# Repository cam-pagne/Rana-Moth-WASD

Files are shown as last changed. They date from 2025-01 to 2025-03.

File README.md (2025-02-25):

# The Rana Labs Moth (WASD Version)

WASD version of [Rana Labs'](https://github.com/rana-sylvatica) Moth, a foldable leverless controller.

<div style="display: flex;">
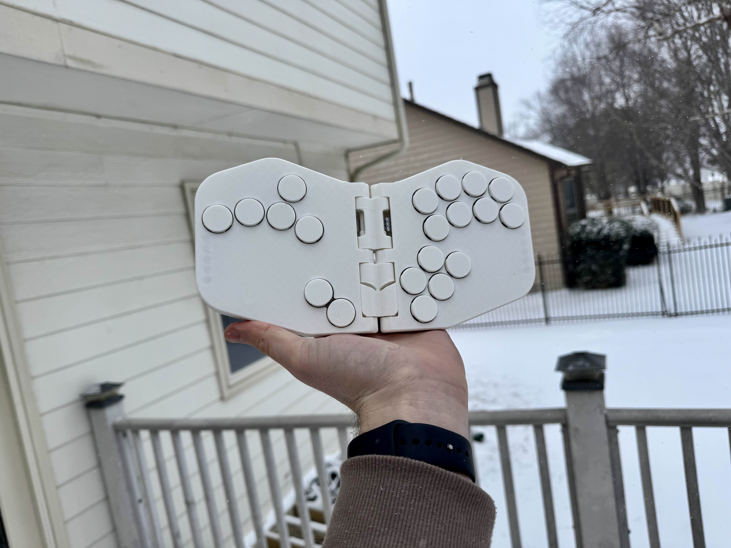
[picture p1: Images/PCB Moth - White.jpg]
Layout 1
    
</div>

---

## Build Overview (What do I need to make one?)

I printed the entire shell, hinges, etc., in **Bambu Lab Matte PLA** (though any PLA should work, build quality feel may vary).

- **Mainboards:** RP2040—**integrated directly onto the left custom PCB.** The right side is connnected by ribbon cable.
- **Switches:** Must be **low profile switches.** I use pretty much any Kailh Choc Low Profile switches. They all work, just choose a preferred switch type.
- **USB-C Connector:** [Quark's](https://github.com/quark-works) and Rana Labs' [QuRB](https://github.com/rana-sylvatica/rana-tadpole/tree/main/PCBs/Breakout%20Board%20(QuRB)), a USB C Breakout board with a ribbon cable port, for solderless assembly.
- **Hardware:** M2 screws and M3 screws are the only fasteners required to assemble. You will need **ten M3 heat inserts** for the backplates, **twelve M3 x 5/6mm bolts** for the backplates and QuRB, and **eight M2 x 4mm bolts** to secure each half of the mainboards.

---

## Assembly

### PCB

To streamline your build, I’ve designed a custom PCB for this controller. This board integrates the Pico directly eliminating the need for any handwiring of the microcontroller. The **only soldering required is the installation of the hotswap sockets for the Choc switches.**

The two halves of the board are connected using a 20 pin, .5 pitch ribbon cable, and the QuRB is connected to the Left side board for USB C port via a 12 pin, .5 pitch ribbon cable.

---

## Magnets

Strong magnets are crucial, as they must counteract every spring in your switches. I used:

- **6x3mm Neodymium magnets**, stacked **2 high** in each of the **10 total holes** (20 magnets overall).
- This setup creates a satisfying snap and keeps the Moth securely folded.

**Amazon link:** [Magnets used](https://www.amazon.com/dp/B096LZNZTQ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)

---

## 'Prism' Ergonomic Mode

For the reverse folded position:

- A **lip** on the two hinge pieces prevents overfolding by creating a defined stopping point.
- The rounded back of the hinges generates friction, ensuring rigidity in the ergonomic 'prism' configuration.

### Adjustments:

- The hinge lip’s width can be edited to modify the folding angle.

---

## Miscellaneous Notes

- **Button Fit:** Ensure buttons sit flush with the face surface when pressed to allow proper folding.
- **Magnet Strength:** Although strong neodymium magnets can overcome minor misalignments, aim for a flush fit.
- **Hinge Pin Slot:** While you can add caps for a cleaner look, the friction fit alone holds securely.

---

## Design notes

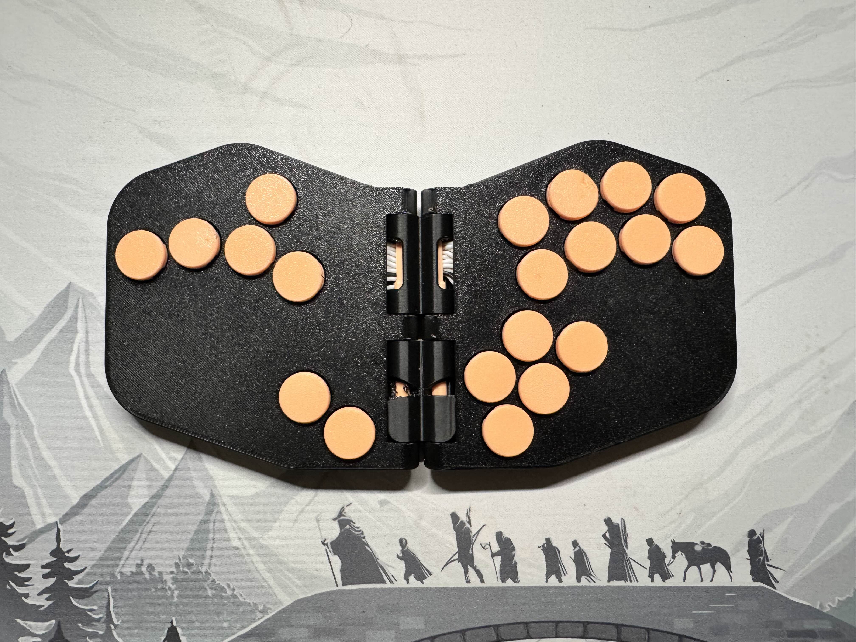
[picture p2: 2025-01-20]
Images/Layout.jpg

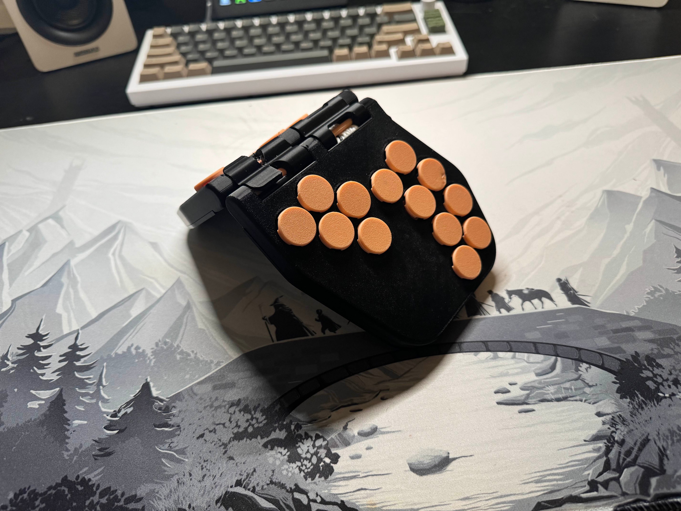
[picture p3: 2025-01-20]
Images/Folded.jpg

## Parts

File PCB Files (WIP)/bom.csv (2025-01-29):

Designator | Footprint | Quantity | Value | LCSC Part #
C1, C10, C2, C4 | 402 | 4 | 1uF | C52923
C11, C12, C13, C14, C15, C16, C17, C3, C5, C6 | 402 | 10 | 100nF | C1525
C7, C8 | 402 | 2 | 22pF | C1555
C9 | 402 | 1 | 10uF | C15525
D1 | D_SOD-123 | 1 | Schottky Diode | C8598
D3 | 805 | 1 | RED | C84256
R10, R11 | 402 | 2 | 1k | C11702
R4 | 402 | 1 | 470 | C25117
R5 | 603 | 1 | 5.6k | C23189
R6 | 603 | 1 | 10k | C25804
R7 | 402 | 1 | 10k | C25744
R8, R9 | RP2040-QFN-56 | 2 | 27 | C25190
SW1 | SW_SPST_SKQG_WithStem | 1 | Boot | C318884
U1 | SOT-23 | 1 | XC6206 | C5446
U2 | FPC-SMD_X05A26H12G | 1 | X05A26H12G | C519263
U3 | RP2040-QFN-56 | 1 | RP2040 | C2040
U4 | SOIC-8_5.23x5.23mm_P1.27mm | 1 | W25Q128JVS | C97521
Y1 | Crystal_SMD_3225-4Pin_3.2x2.5mm | 1 | 12MHz | C9002
J4, J5 | XUNPU FPC-05F-20PH20 | 2 | FPC-05F-20PH20 | C2856803

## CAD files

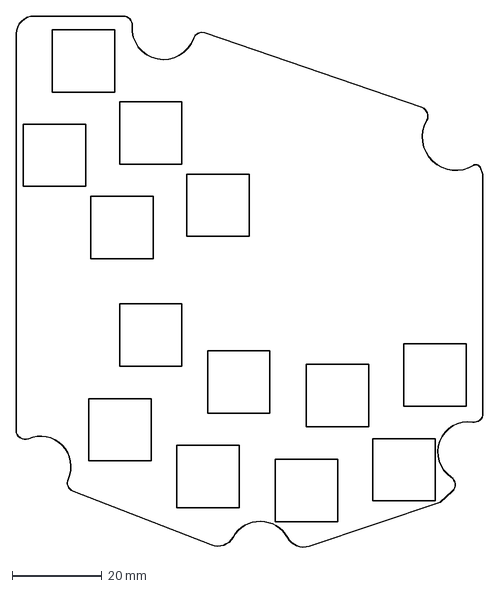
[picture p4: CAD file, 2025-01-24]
DXFs/Right PCB (Button Outlines).dxf
104.0 x 118.7 mm

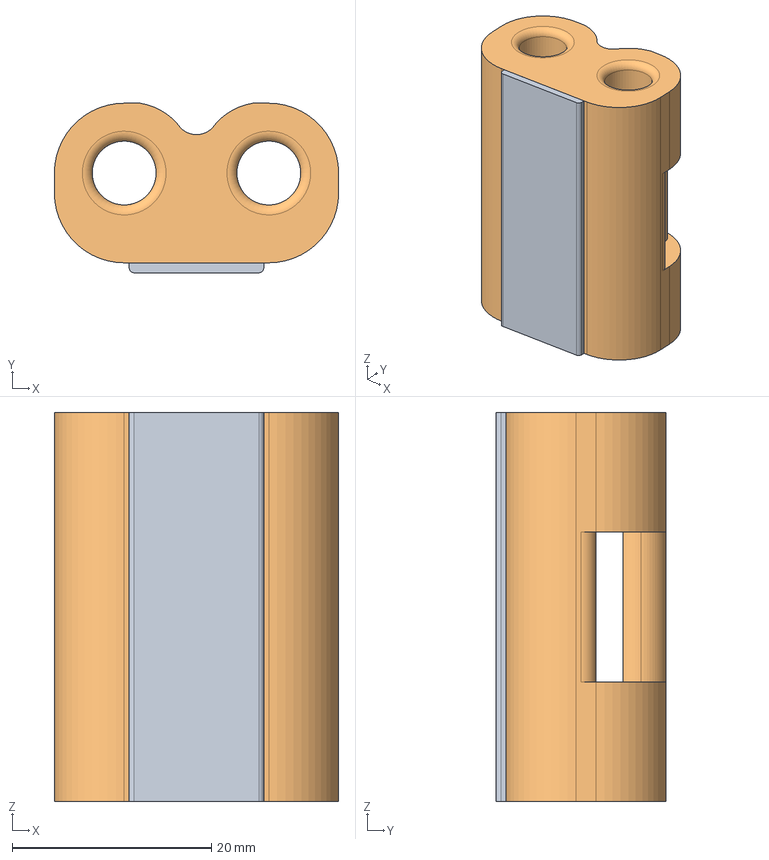
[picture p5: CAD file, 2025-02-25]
Hinge and Buttons/Hinge Upper.step
28.5 x 17.0 x 39.0 mm

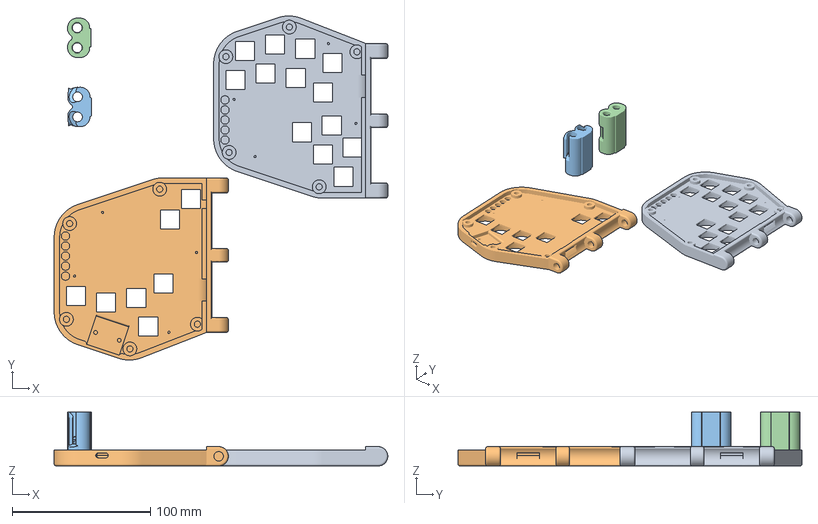
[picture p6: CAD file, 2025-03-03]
Shell/Top Shell and Hinges.3mf
241.3 x 248.8 x 39.0 mm
Moth Top Right.step
Moth Top Left.step
Hinge Lower.step
Hinge Upper.step

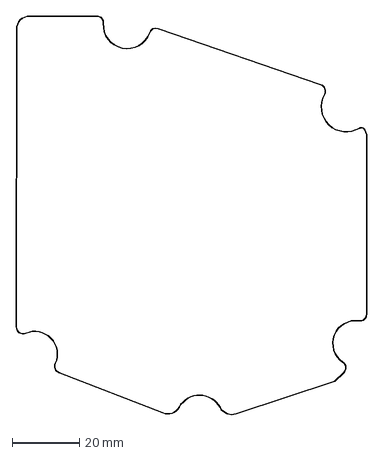
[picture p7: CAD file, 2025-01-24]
DXFs/Right PCB.dxf
104.0 x 118.7 mm

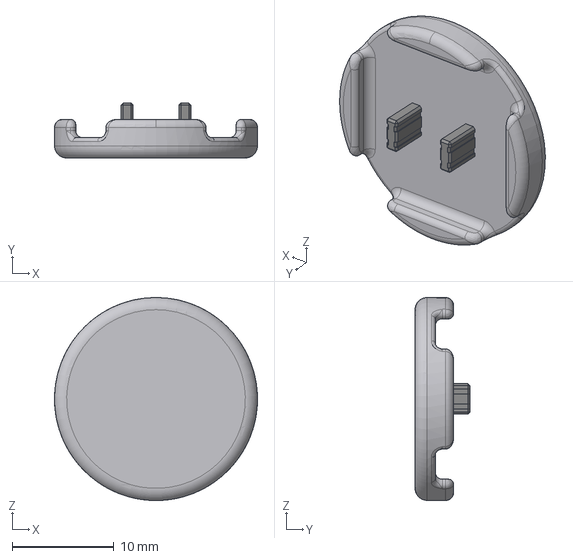
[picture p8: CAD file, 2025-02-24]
Hinge and Buttons/Choc v1 Keycaps.step
20.0 x 5.41 x 20.0 mm
Kailh Choc FunkMonk 1u.step
Folder 03

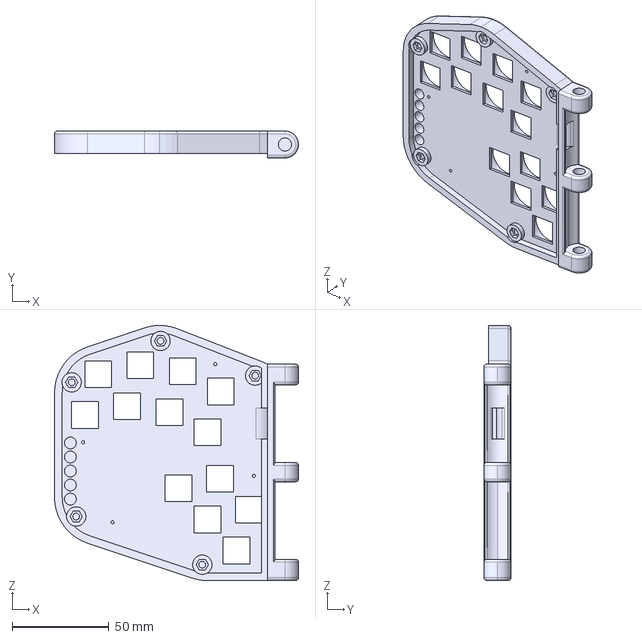
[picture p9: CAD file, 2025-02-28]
Shell/Moth Top Right.step
126.0 x 14.0 x 131.8 mm

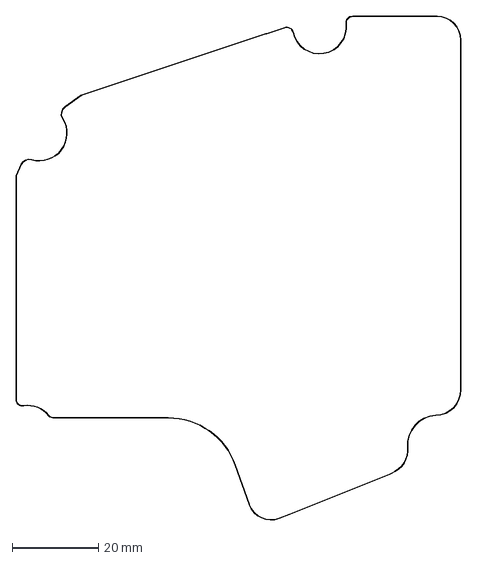
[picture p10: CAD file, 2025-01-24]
DXFs/Left PCB.dxf
103.0 x 116.8 mm

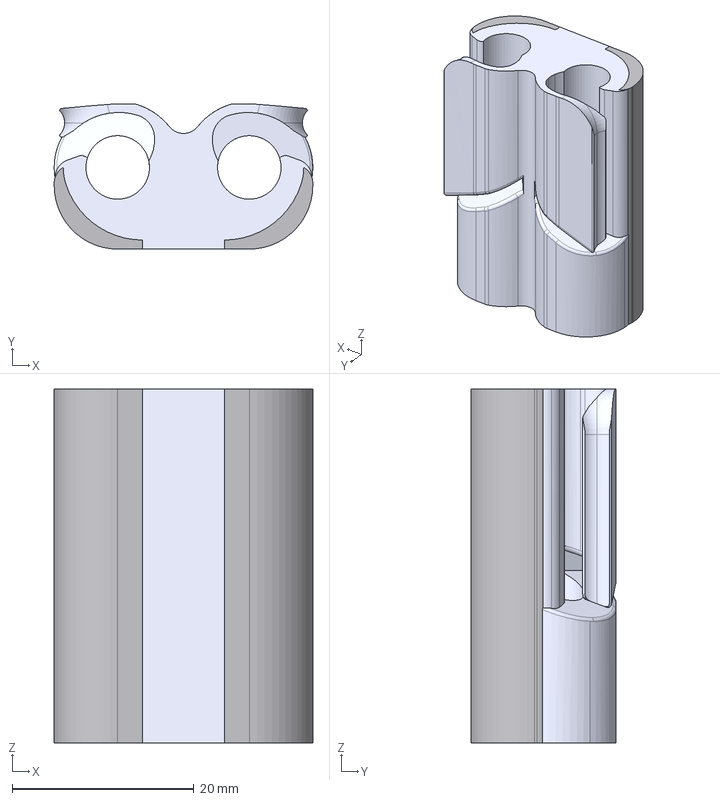
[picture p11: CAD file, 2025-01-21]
Hinge and Buttons/Hinge Lower.step
28.5 x 16.0 x 39.0 mm

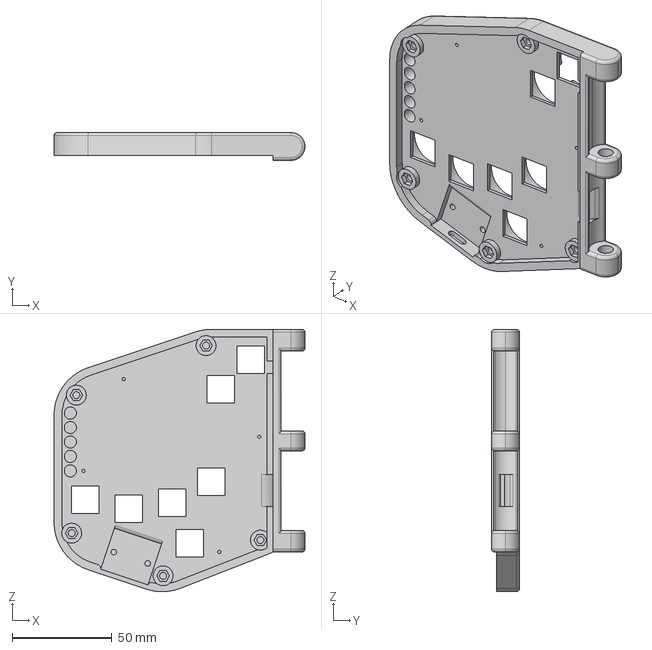
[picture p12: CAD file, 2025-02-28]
Shell/Moth Top Left.step
126.0 x 14.0 x 131.8 mm
QuRB and Reshape
Top Left Moth CTM v19.step

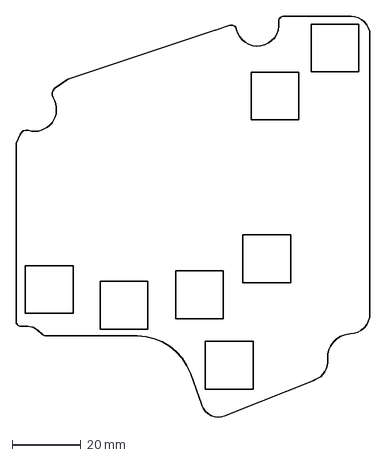
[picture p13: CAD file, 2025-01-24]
DXFs/Left PCB (Button Outlines).dxf
103.0 x 116.8 mm

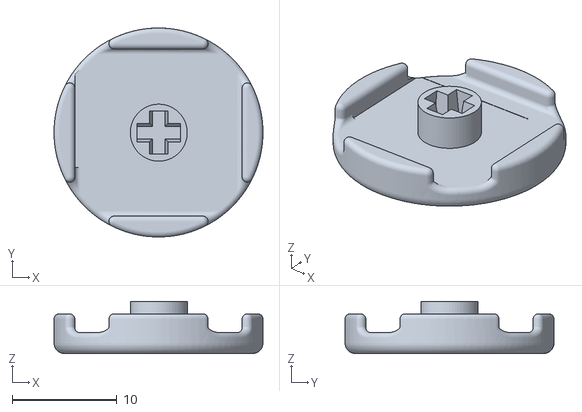
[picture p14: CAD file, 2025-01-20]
Hinge and Buttons/Keycaps.stl
20.0 x 20.0 x 4.98

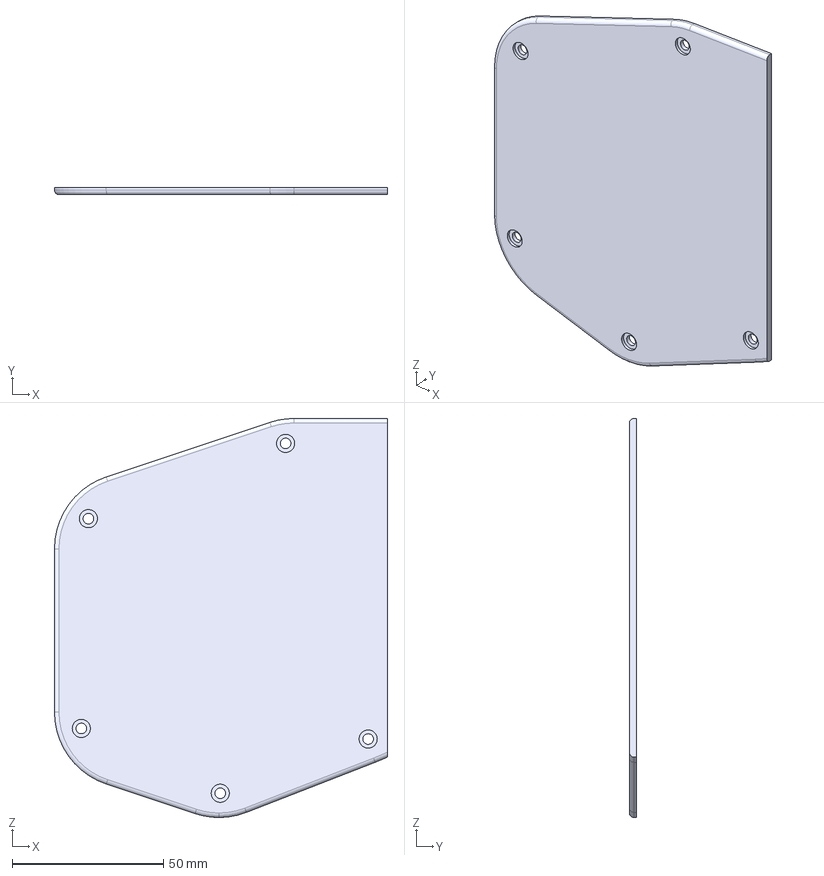
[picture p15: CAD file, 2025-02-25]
Shell/Bottom Left.step
110.0 x 2.40 x 131.8 mm

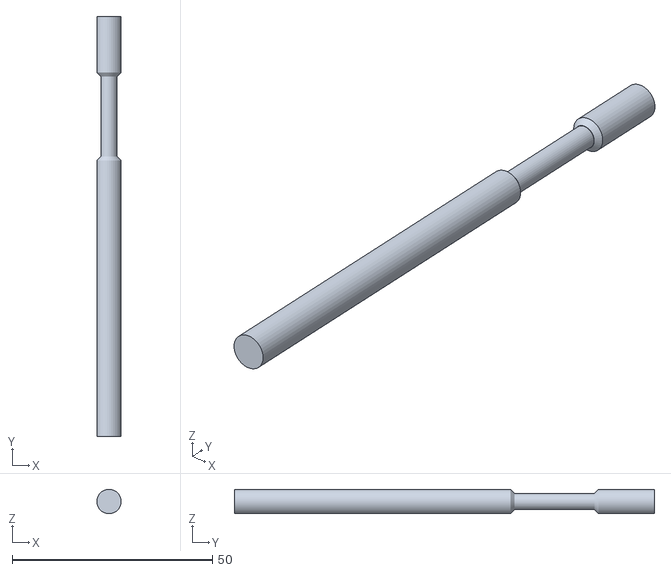
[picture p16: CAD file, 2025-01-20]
Hinge and Buttons/Hinge Pin.STL
6.10 x 105.0 x 6.10

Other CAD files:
Shell/Bottom Right.step

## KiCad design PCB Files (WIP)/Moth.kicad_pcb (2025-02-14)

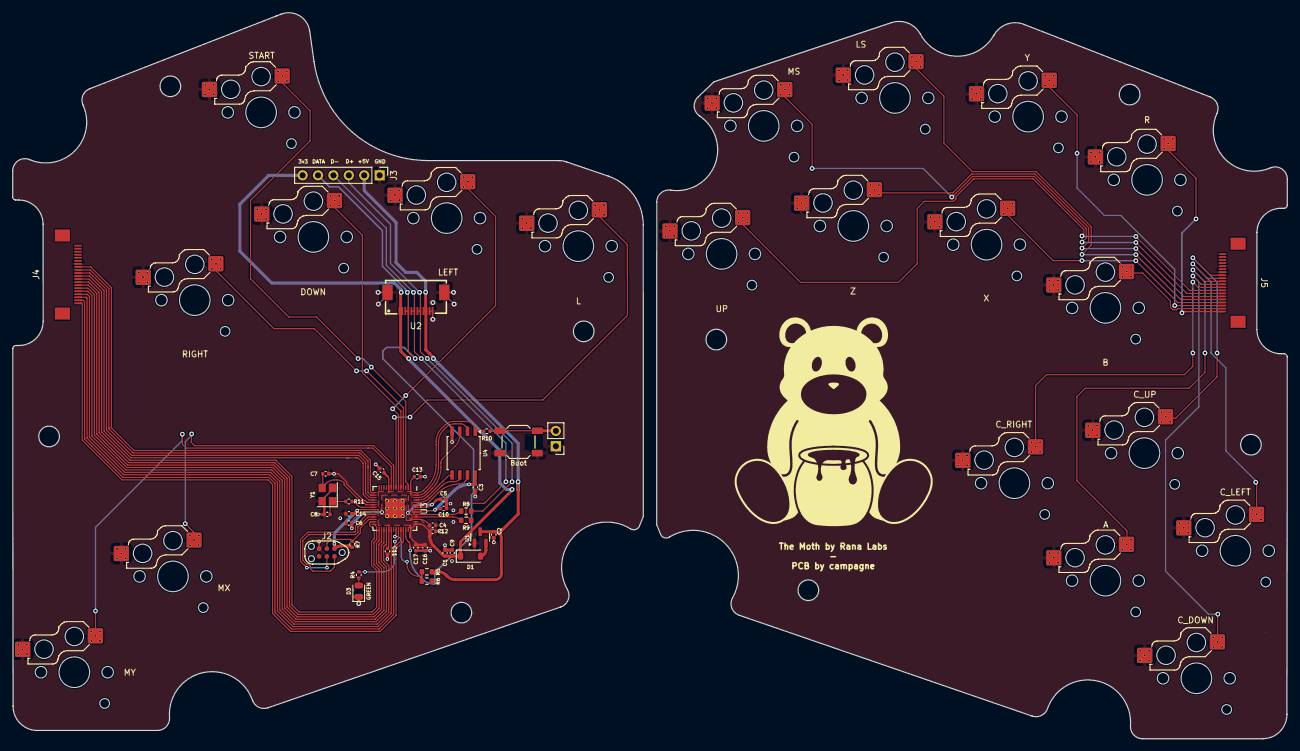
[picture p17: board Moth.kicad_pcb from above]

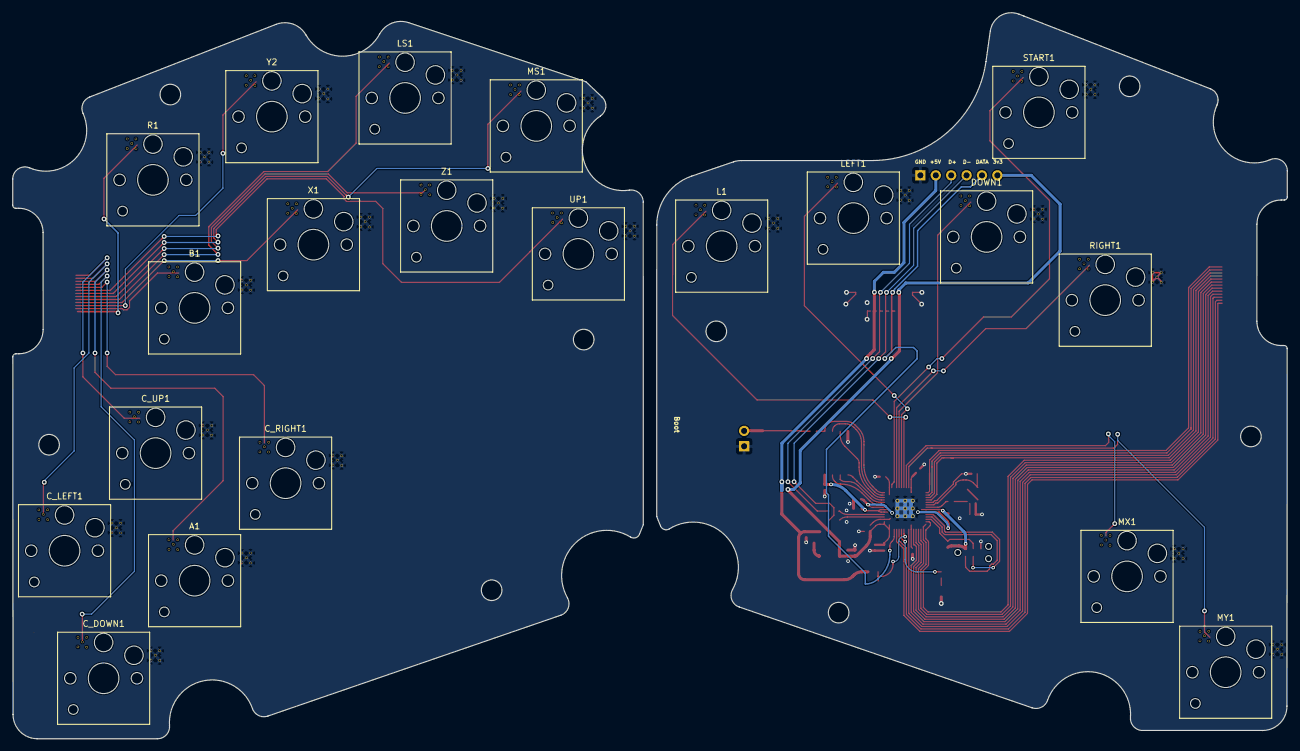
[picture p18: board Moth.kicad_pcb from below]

Board: 2 copper layers, 210.2 x 119.7 mm, 58 parts (20 on the bottom side), 59 nets.

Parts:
A1: A; SW_Hotswap_Kailh_Choc_V1V2_THT
B1: B; SW_Hotswap_Kailh_Choc_V1V2_THT
C1, C2, C4, C10: 1uF; C_0402_1005Metric
C3, C5, C6, C11, C12, C13, C14, C15, C16, C17: 100nF; C_0402_1005Metric
C7, C8: 22pF; C_0402_1005Metric
C9: 10uF; C_0402_1005Metric
C_DOWN1: C Down; SW_Hotswap_Kailh_Choc_V1V2_THT
C_LEFT1: C Left; SW_Hotswap_Kailh_Choc_V1V2_THT
C_RIGHT1: C Right; SW_Hotswap_Kailh_Choc_V1V2_THT
C_UP1: C Up; SW_Hotswap_Kailh_Choc_V1V2_THT
D1: Schottky Diode; D_SOD-123
D3: GREEN; LED_0805_2012Metric
DOWN1: Down; SW_Hotswap_Kailh_Choc_V1V2_THT
J1: Conn_01x02; PinHeader_1x02_P2.54mm_Vertical
J2: JTAG_TC2030; CON_TC2030_outlined
J3: DuPont Connector; PinHeader_1x06_P2.54mm_Vertical
J4: Left Ribbon; FPC-05F-30PH20
J5: Right Ribbon; FPC-05F-30PH20
L1: L; SW_Hotswap_Kailh_Choc_V1V2_THT
LEFT1: Left; SW_Hotswap_Kailh_Choc_V1V2_THT
LS1: LS; SW_Hotswap_Kailh_Choc_V1V2_THT
MS1: MS; SW_Hotswap_Kailh_Choc_V1V2_THT
MX1: MX; SW_Hotswap_Kailh_Choc_V1V2_THT
MY1: MY; SW_Hotswap_Kailh_Choc_V1V2_THT
R1: R; SW_Hotswap_Kailh_Choc_V1V2_THT
R4: 470; R_0402_1005Metric
R5: 5.6k; R_0603_1608Metric
R6: 10k; R_0603_1608Metric
R7: 10k; R_0402_1005Metric
R8, R9: 27; R_0603_1608Metric
R10, R11: 1k; R_0402_1005Metric
RIGHT1: Right; SW_Hotswap_Kailh_Choc_V1V2_THT
START1: Start; SW_Hotswap_Kailh_Choc_V1V2_THT
SW1: Boot; SW_SPST_SKQG_WithStem
U1: XC6206; SOT-23
U2: X05A26H12G; FPC-SMD_X05A26H12G
U3: RP2040; RP2040-QFN-56
U4: W25Q128JVS; SOIC-8_5.23x5.23mm_P1.27mm
UP1: Up; SW_Hotswap_Kailh_Choc_V1V2_THT
X1: X; SW_Hotswap_Kailh_Choc_V1V2_THT
Y1: 12MHz; Crystal_SMD_3225-4Pin_3.2x2.5mm
Y2: Y; SW_Hotswap_Kailh_Choc_V1V2_THT
Z1: Z; SW_Hotswap_Kailh_Choc_V1V2_THT

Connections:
3vDiode: C1.2, C3.1, C9.1, C10.1, C11.1, C12.1, C13.1, C14.1, C15.1, C16.1, C17.1, D1.1 (K), J2.1 (VCC), J3.6, R7.1, U2.1, U2.2, U3.1 (IOVDD), U3.10 (IOVDD), U3.22 (IOVDD), U3.33 (IOVDD), U3.42 (IOVDD), U3.43 (ADC_AVDD), U3.44 (VREG_VIN), U3.48 (USB_VDD), U3.49 (IOVDD), U4.8 (VCC)
+1V1: C4.1, C5.1, C6.1, U3.23 (DVDD), U3.45 (VREG_VOUT), U3.50 (DVDD)
+5V: C2.2, J3.2, R5.1, U1.3 (VI), U2.9, U2.10
/D_+: R8.2, U3.47 (D+)
/D_-: R9.2, U3.46 (D-)
/XTAL_O: C8.2, R11.1, Y1.1
/~USB_BOOT: J1.2, R10.1, SW1.2
A: A1.1, J5.11
A RIBBON: J4.10, U3.17 (GPIO14)
B: B1.1, J5.2
B RIBBON: J4.19, U3.38 (GPIO26/ADC0)
CS: R10.2, U3.56 (QSPI_SS_N), U4.1 (~CS)
C_DN: C_DOWN1.1, J5.10
C_DN RIBBON: J4.11, U3.18 (GPIO15)
C_LT: C_LEFT1.1, J5.12
C_LT RIBBON: J4.9, U3.16 (GPIO13)
C_RT: C_RIGHT1.1, J5.9
C_RT RIBBON: J4.12, U3.27 (GPIO16)
C_UP: C_UP1.1, J5.13
C_UP RIBBON: J4.8, U3.15 (GPIO12)
D+: J3.3, R8.1, U2.7, U2.8
D-: J3.4, R9.1, U2.5, U2.6
DATA: J3.5, U2.3, U2.4, U3.40 (GPIO28/ADC2)
DOWN: DOWN1.1, U3.5 (GPIO3)
GND: A1.2, B1.2, C1.1, C2.1, C3.2, C4.2, C5.2, C6.2, C7.1, C8.1, C9.2, C10.2, C11.2, C12.2, C13.2, C14.2, C15.2, C16.2, C17.2, C_DOWN1.2, C_LEFT1.2, C_RIGHT1.2, C_UP1.2, D3.1 (K), DOWN1.2, J1.1, J2.5 (GND), J3.1, J4.7, J5.14, L1.2, LEFT1.2, LS1.2, MS1.2, MX1.2, MY1.2, R1.2, R6.2, RIGHT1.2, START1.2, SW1.1, U1.1 (GND), U2.11, U2.12, U2.13, U2.14, U3.19 (TESTEN), U3.57 (GND), U4.4 (GND), UP1.2, X1.2, Y1.2, Y1.4, Y2.2, Z1.2
L: L1.1, U3.7 (GPIO5)
LEFT: LEFT1.1, U3.6 (GPIO4)
LS: J5.5, LS1.1
LS RIBBON: J4.16, U3.31 (GPIO20)
M1: MX1.1, U3.8 (GPIO6)
M2: MY1.1, U3.9 (GPIO7)
MS: J5.7, MS1.1
MS RIBBON: J4.14, U3.29 (GPIO18)
unnamed: D1.2 (A), U1.2 (VO)
unnamed: D3.2 (A), R4.2
PICO_LED: R4.1, U3.37 (GPIO25)
QSPI_CLK: U3.52 (QSPI_SCLK), U4.6 (CLK)
R: J5.1, R1.1
R RIBBON: J4.20, U3.39 (GPIO27/ADC1)
RIGHT: RIGHT1.1, U3.4 (GPIO2)
SD0: U3.53 (QSPI_SD0), U4.5 (DI(IO0))
SD1: U3.55 (QSPI_SD1), U4.2 (DO(IO1))
SD2: U3.54 (QSPI_SD2), U4.3 (IO2)
SD3: U3.51 (QSPI_SD3), U4.7 (IO3)
START: START1.1, U3.2 (GPIO0)
SWCLK: J2.4 (SWCLK), U3.24 (SWCLK)
SWD: J2.2 (SWDIO), U3.25 (SWDIO)
UP: J5.8, UP1.1
UP RIBBON: J4.13, U3.28 (GPIO17)
VBUS_SENSE: R5.2, R6.1, U3.36 (GPIO24)
X: J5.4, X1.1
X RIBBON: J4.17, U3.32 (GPIO21)
XTAL_IN: C7.2, U3.20 (XTAL_IN), Y1.3
XTAL_OUT: R11.2, U3.21 (XTAL_OUT)
Y: J5.3, Y2.1
Y RIBBON: J4.18, U3.34 (GPIO22)
Z: J5.6, Z1.1
Z RIBBON: J4.15, U3.30 (GPIO19)
~RESET: J2.3 (~RST), R7.2, U3.26 (~RUN)

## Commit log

2025-01-21 Add files via upload
    Increased the size of the bottom hinge to add more friction in prism mode
    [Hinge Lower.step]
2025-01-22 Added DXF files for PCB creation.
    [Moth Top Left.dxf, Moth Top Right.dxf]
2025-01-22 Added DXFs for the possible creation of a PCB for the Moth.
2025-01-24 Reconfigured PCB, closer to completion.
    [Moth.kicad_pcb, Moth.kicad_sch]
2025-01-25 Completed PCB pending review
    [Moth.kicad_pcb, Moth.kicad_sch]
2025-01-29 PCB files possibly done pending testing
    [Moth.csv, Moth.kicad_pcb, positions.csv]
